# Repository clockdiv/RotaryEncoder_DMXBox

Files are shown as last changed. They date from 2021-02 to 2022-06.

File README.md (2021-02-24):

# RotaryEncoder_DMXBox
a small machine with rotary encoders to controll DMX devices

* PCB created in KiCad 5.1.9
* Code written in vscode with PlatformIO
* based on the Teensy 3.2 Project by pjrc.com

## Basic function
The values of the rotary encoders are mapped to specific DMX channels. The idea is to create a device for interactive stages like e.g. a pully hanging from the ceiling to control moving lights or similiar with it.

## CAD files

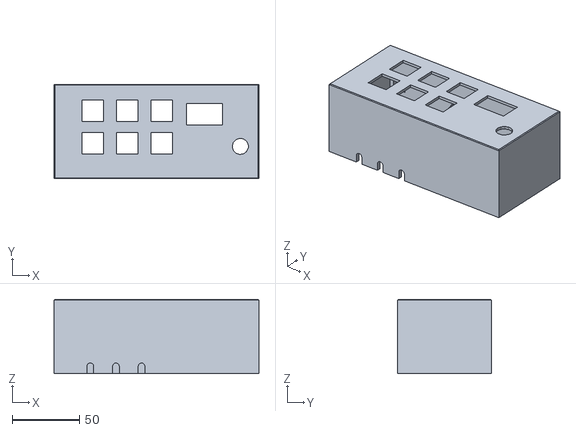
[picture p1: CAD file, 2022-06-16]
box/20210312 Gehäuse.stl
152.0 x 70.0 x 55.0

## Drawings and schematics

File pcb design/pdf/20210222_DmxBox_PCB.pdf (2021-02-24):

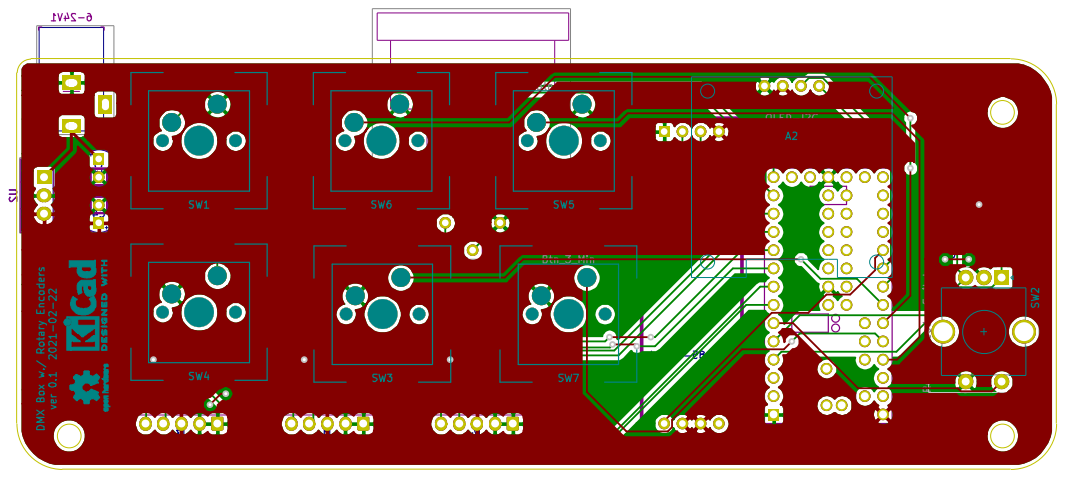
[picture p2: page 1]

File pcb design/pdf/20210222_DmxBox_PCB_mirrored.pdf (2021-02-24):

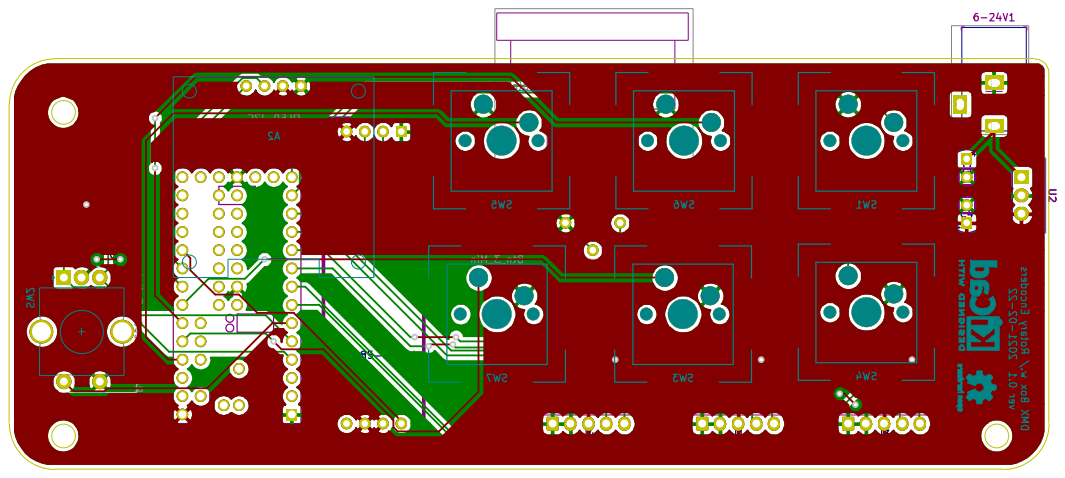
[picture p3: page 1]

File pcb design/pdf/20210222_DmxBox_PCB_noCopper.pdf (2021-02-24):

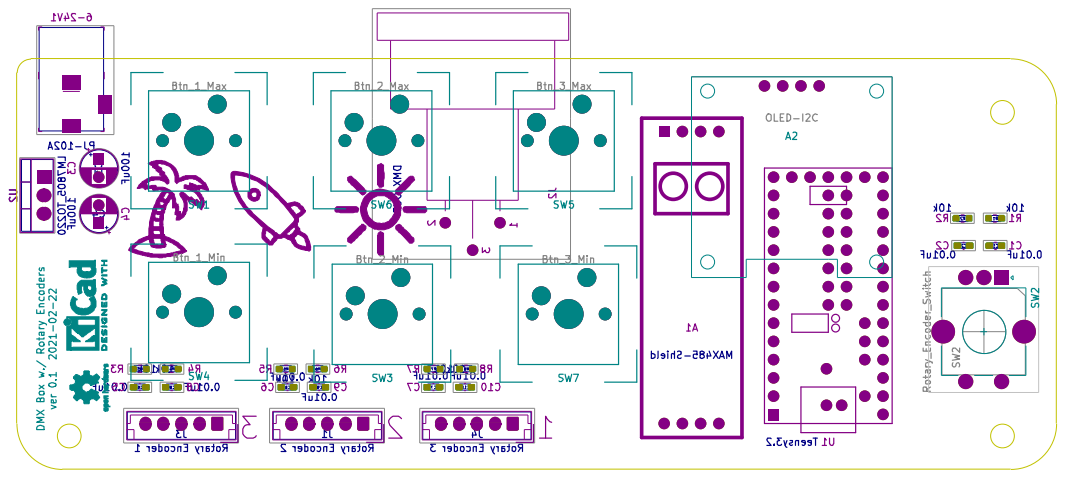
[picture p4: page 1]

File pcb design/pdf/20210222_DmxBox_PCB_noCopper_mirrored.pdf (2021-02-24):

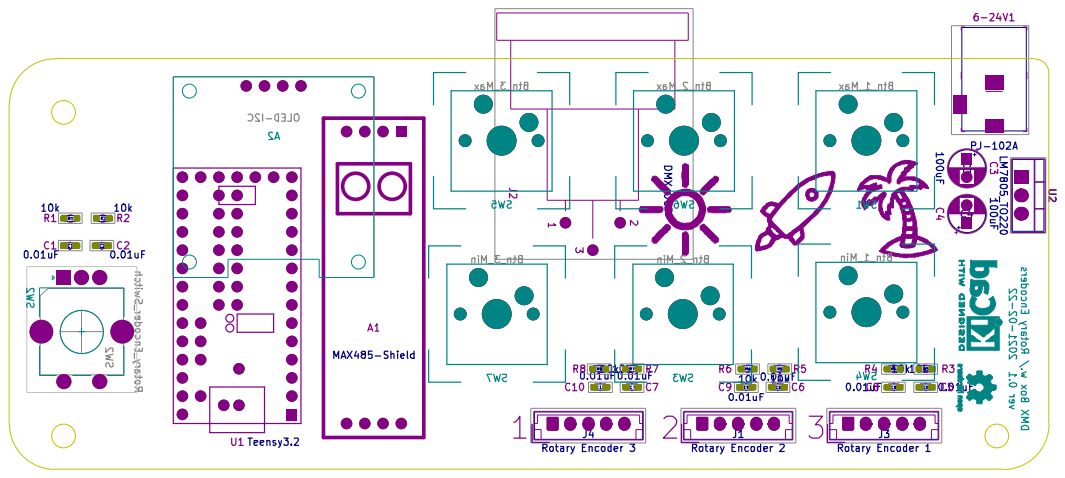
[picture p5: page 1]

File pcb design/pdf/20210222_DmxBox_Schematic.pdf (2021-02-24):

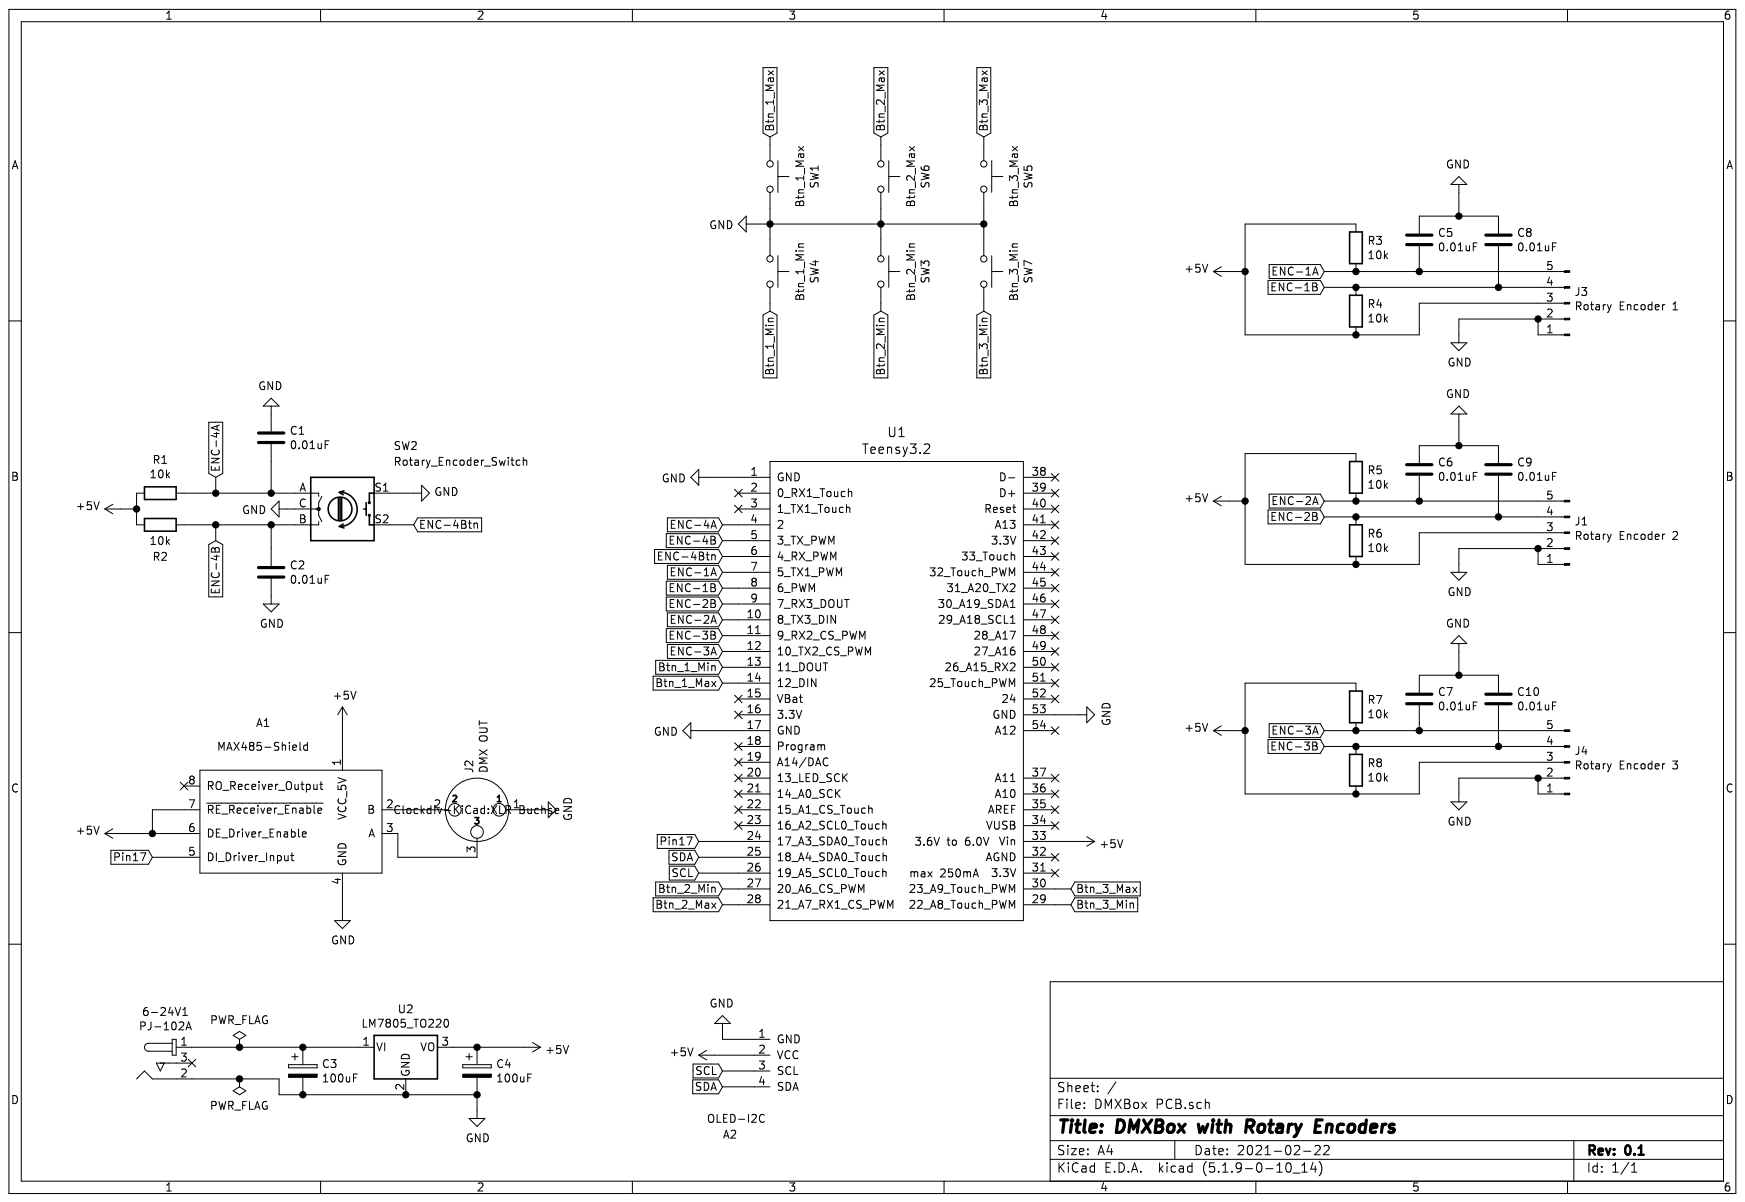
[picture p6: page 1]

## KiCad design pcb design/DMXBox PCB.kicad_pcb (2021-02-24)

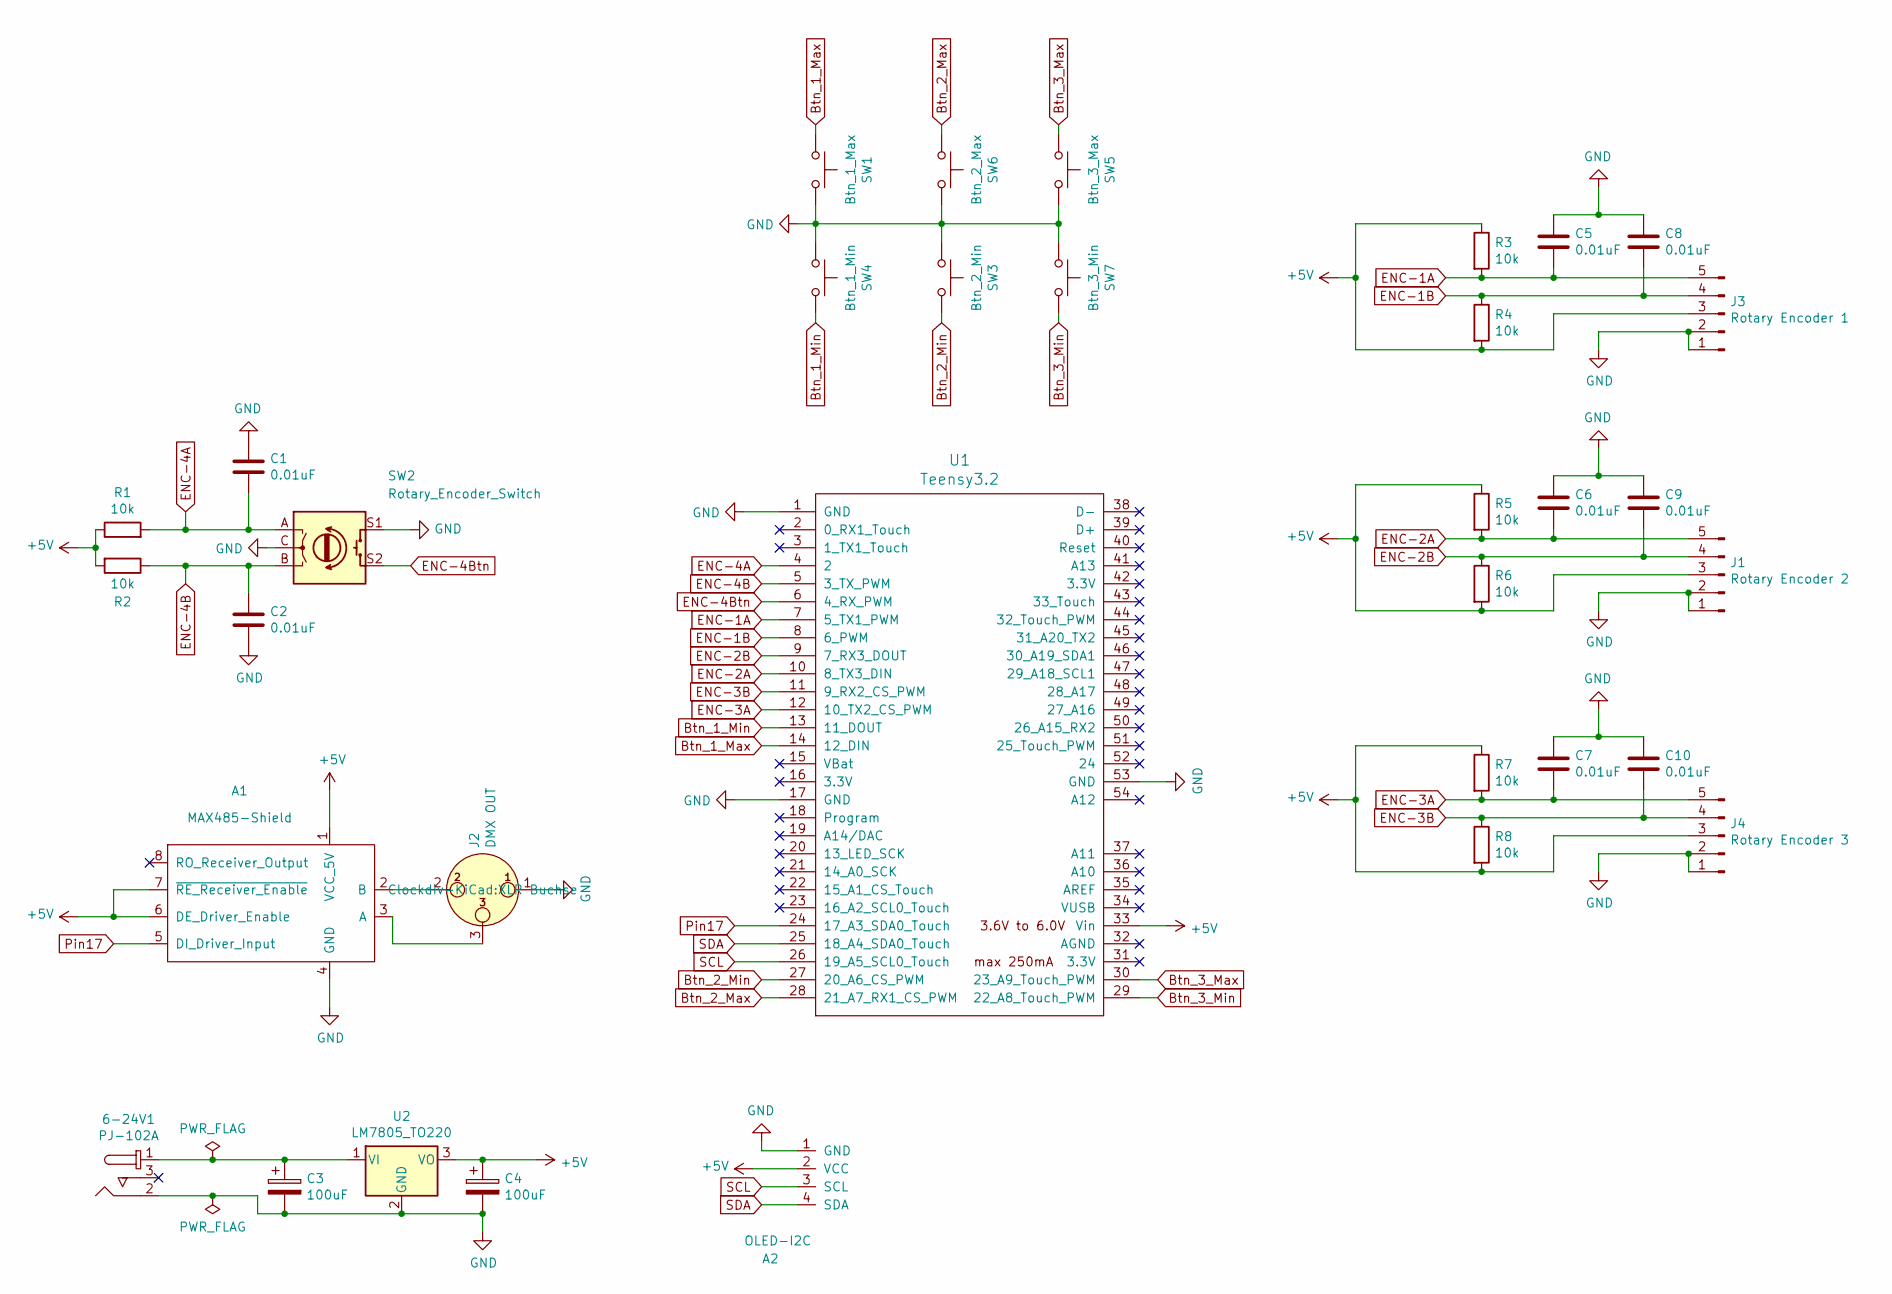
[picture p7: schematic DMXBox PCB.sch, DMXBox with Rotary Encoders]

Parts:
6-24V1: PJ-102A; Barrel_Jack_5.5mmODx2.1mmID_PJ-102A; MPN PJ-102A; Digi-Key_PN CP-102A-ND
A1: MAX485-Shield
A2: OLED-I2C
C1, C2, C5, C6, C7, C8, C9, C10: 0.01uF; C_0603_1608Metric_Pad1.08x0.95mm_HandSolder
C3, C4: 100uF; CP_Radial_D5.0mm_P2.50mm
J1: Rotary Encoder 2; JST_EH_B5B-EH-A_1x05_P2.50mm_Vertical
J2: DMX OUT; XLR Buchse
J3: Rotary Encoder 1; JST_EH_B5B-EH-A_1x05_P2.50mm_Vertical
J4: Rotary Encoder 3; JST_EH_B5B-EH-A_1x05_P2.50mm_Vertical
R1, R2, R3, R4, R5, R6, R7, R8: 10k; R_0603_1608Metric_Pad0.98x0.95mm_HandSolder
SW1: Btn_1_Max; CherryMX_PCBmount_NoDiodeNoLED
SW2: Rotary_Encoder_Switch; RotaryEncoder_Alps_EC11E-Switch_Vertical_H20mm_CircularMoun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
SW3: Btn_2_Min; CherryMX_PCBmount_NoDiodeNoLED
SW4: Btn_1_Min; CherryMX_PCBmount_NoDiodeNoLED
SW5: Btn_3_Max; CherryMX_PCBmount_NoDiodeNoLED
SW6: Btn_2_Max; CherryMX_PCBmount_NoDiodeNoLED
SW7: Btn_3_Min; CherryMX_PCBmount_NoDiodeNoLED
U1: Teensy3.2; Teensy30_31_32_All_Pins
U2: LM7805_TO220; TO-220-3_Vertical

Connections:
+5V: A1.1 (VCC_5V), A1.6 (DE_Driver_Enable), A1.7 (~RE_Receiver_Enable), A2.2 (VCC), C4.1, J1.3, J3.3, J4.3, R1.1, R2.2, R3.1, R4.2, R5.1, R6.2, R7.1, R8.2, U1.33 (Vin), U2.3 (VO)
Btn_1_Max: SW1.1, U1.14 (12_DIN)
Btn_1_Min: SW4.2, U1.13 (11_DOUT)
Btn_2_Max: SW6.1, U1.28 (21_A7_RX1_CS_PWM)
Btn_2_Min: SW3.2, U1.27 (20_A6_CS_PWM)
Btn_3_Max: SW5.1, U1.30 (23_A9_Touch_PWM)
Btn_3_Min: SW7.2, U1.29 (22_A8_Touch_PWM)
ENC-1A: C5.2, J3.5, R3.2, U1.7 (5_TX1_PWM)
ENC-1B: C8.2, J3.4, R4.1, U1.8 (6_PWM)
ENC-2A: C6.2, J1.5, R5.2, U1.10 (8_TX3_DIN)
ENC-2B: C9.2, J1.4, R6.1, U1.9 (7_RX3_DOUT)
ENC-3A: C7.2, J4.5, R7.2, U1.12 (10_TX2_CS_PWM)
ENC-3B: C10.2, J4.4, R8.1, U1.11 (9_RX2_CS_PWM)
ENC-4A: C1.2, R1.2, SW2.A, U1.4 (2)
ENC-4B: C2.1, R2.1, SW2.B, U1.5 (3_TX_PWM)
ENC-4Btn: SW2.S2, U1.6 (4_RX_PWM)
GND: 6-24V1.2, A1.4 (GND), A2.1 (GND), C1.1, C2.2, C3.2, C4.2, C5.1, C6.1, C7.1, C8.1, C9.1, C10.1, J1.1, J1.2, J2.1, J3.1, J3.2, J4.1, J4.2, SW1.2, SW2.C, SW2.S1, SW3.1, SW4.1, SW5.2, SW6.2, SW7.1, U1.1 (GND), U1.17 (GND), U1.53 (GND), U2.2 (GND)
unnamed: 6-24V1.1, C3.1, U2.1 (VI)
unnamed: A1.2 (B), J2.2
unnamed: A1.3 (A), J2.3
Pin17: A1.5 (DI_Driver_Input), U1.24 (17_A3_SDA0_Touch)
SCL: A2.3 (SCL), U1.26 (19_A5_SCL0_Touch)
SDA: A2.4 (SDA), U1.25 (18_A4_SDA0_Touch)

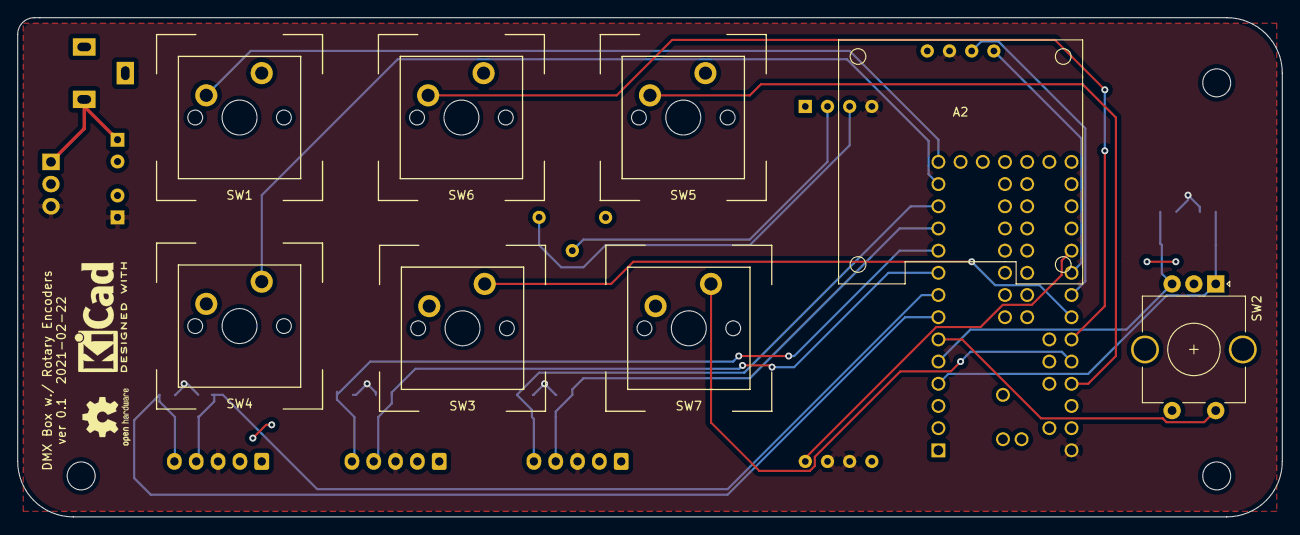
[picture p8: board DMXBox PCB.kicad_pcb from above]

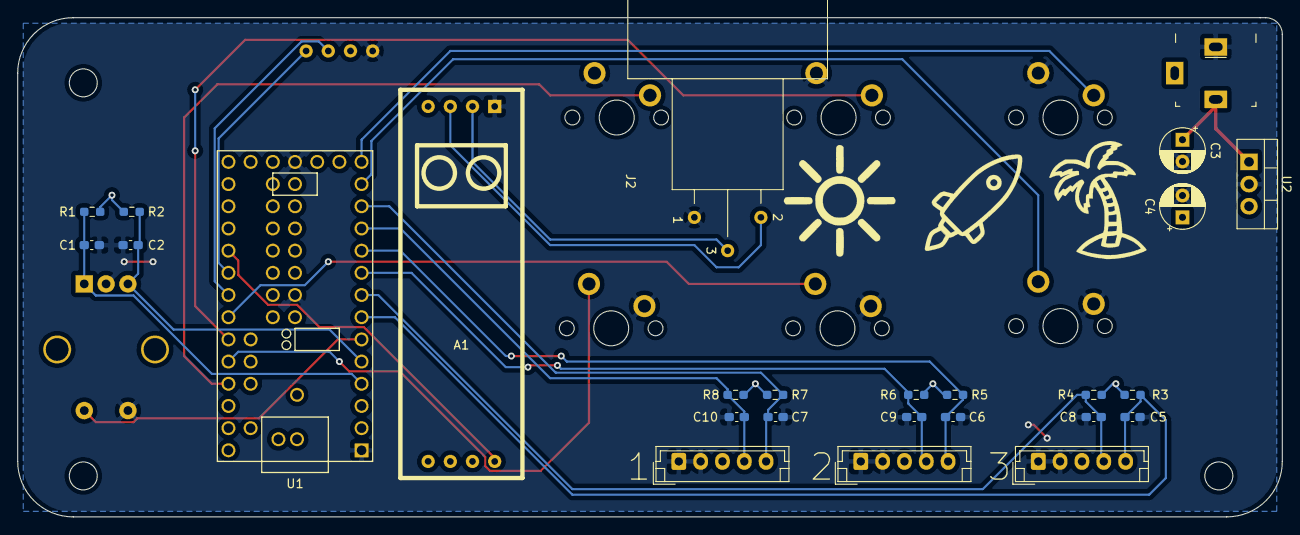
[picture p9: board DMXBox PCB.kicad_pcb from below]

Board: 2 copper layers, 144.8 x 57.2 mm, 34 parts (26 on the bottom side), 23 nets.

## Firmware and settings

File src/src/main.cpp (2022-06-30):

#include <SPI.h>
#include <Wire.h>
#include <Adafruit_GFX.h>
#include <Adafruit_SSD1306.h>
#include <Encoder.h>
#include <Bounce2.h>
#include <DmxSimple.h>
#include "Axis.h"

#define SCREEN_ADDRESS 0x3C

#define DEBOUNCEINTERVAL 20

Adafruit_SSD1306 display(128, 64, &Wire, -1);

Encoder encoder(3, 2);
Encoder encoderX(6, 5);
Encoder encoderY(8, 7);
Encoder encoderZ(10, 9);

Bounce selectButton = Bounce();
Bounce buttonXUp = Bounce();
Bounce buttonXDown = Bounce();
Bounce buttonYUp = Bounce();
Bounce buttonYDown = Bounce();
Bounce buttonZUp = Bounce();
Bounce buttonZDown = Bounce();

Axis axisX, axisY, axisZ;

int32_t encoderValue  = -999;

enum statesEnum {IDLE, WAIT_FOR_BUTTON, WAIT_FOR_BUTTON_TIMEOUT, SET_DMX_CHANNEL};
uint8_t state = IDLE, nextState = IDLE;

Axis* selectedAxis = &axisX;

unsigned long currentMillis, stateEnteredMillis, lastTimeValueSend;
unsigned long waitForButtonTimeout = 1000;
unsigned long sendValueInterval = 1000/25;
Axis* axisSetup;

void displayValues() {
    display.clearDisplay();
    display.invertDisplay(false);

    display.setTextSize(1); // Draw 2X-scale text
    display.setTextColor(SSD1306_WHITE);
    display.setCursor(0, 0);

    display.print(axisX.getValue());
    display.print(" => ");
    display.print(axisX.getDMXValue());
    display.print(" (ch: ");
    display.print(axisX.getDMXChannel());
    display.print(")");
    display.println();

    display.print(axisY.getValue());
    display.print(" => ");
    display.print(axisY.getDMXValue());
    display.print(" (ch: ");
    display.print(axisY.getDMXChannel());
    display.print(")");
    display.println();

    display.print(axisZ.getValue());
    display.print(" => ");
    display.print(axisZ.getDMXValue());
    display.print(" (ch: ");
    display.print(axisZ.getDMXChannel());
    display.print(")");
    display.println();

    display.display();      // Show initial text
}

void sendDMX() {
    DmxSimple.write(axisX.getDMXChannel(), axisX.getDMXValue());
    DmxSimple.write(axisY.getDMXChannel(), axisY.getDMXValue());
    DmxSimple.write(axisZ.getDMXChannel(), axisZ.getDMXValue());
}

void displayInfoMsg(String msg) {
    display.clearDisplay();
    display.setTextSize(2);
    display.invertDisplay(true);
    display.setCursor(0, 24);
    display.println(msg);
    display.display();
}

void stateMachineRun() {
  switch (state)
  {

  case IDLE:
    // send DMX Values if one axis has changed
    if (axisX.changed() || axisY.changed() || axisZ.changed()) {
      displayValues();
      sendDMX();
    }
    if(selectButton.fallingEdge()){
      stateEnteredMillis = millis();
      nextState = SET_DMX_CHANNEL;
      state = WAIT_FOR_BUTTON;
    }

    // Send Axis to Serial
    if (currentMillis - lastTimeValueSend > sendValueInterval) {
      Serial.println(axisZ.getValue());
      lastTimeValueSend = currentMillis;
    }
    
    break;



  case WAIT_FOR_BUTTON:
    displayInfoMsg("Press 1s");
    if( currentMillis - waitForButtonTimeout > stateEnteredMillis /*|| buttonXUp.risingEdge() || buttonXDown.risingEdge() || buttonYUp.risingEdge() || buttonYDown.risingEdge() || buttonZUp.risingEdge() || buttonZDown.risingEdge()*/) {
      Serial.print("next state: ");
      Serial.println(nextState);
      state = nextState;
    }
    break;
   

  case SET_DMX_CHANNEL:
    if(selectButton.fallingEdge()){
      stateEnteredMillis = millis();
      nextState = IDLE;
      state = WAIT_FOR_BUTTON;
    }


      int32_t newencoderValue;
      newencoderValue = encoder.read() / 4;
      //delay(200);
      if(newencoderValue != encoderValue )
      {
        Serial.println(newencoderValue);
        encoderValue = newencoderValue;
      /*
        axisSetup->setDMXChannel(constrain(encoderValue, 0, 512));
        display.clearDisplay();
        display.setCursor(0,0);
        display.println(axisSetup->name);
        display.print("ch: ");
        display.println(axisSetup->getDMXChannel());
        display.print("enc: ");
        display.println(encoderValue);
        display.display();
        */
      }
      
    break;
  
  default:
    break;
  }
}

void setup() {
  Serial.begin(115200);
  //while (!Serial);
  Serial.println("Welcome!");
  DmxSimple.usePin(17);
  //DmxSimple.maxChannel(3);

  axisX.setDMXChannel(1);
  axisY.setDMXChannel(2);
  axisZ.setDMXChannel(3);
  axisX.name = "x-axis";
  axisY.name = "y-axis";
  axisZ.name = "z-axis";


  selectButton.attach(4, INPUT_PULLUP);
  selectButton.interval(DEBOUNCEINTERVAL);

  buttonXUp.attach(11, INPUT_PULLUP);
  buttonXUp.interval(DEBOUNCEINTERVAL);

  buttonXDown.attach(12, INPUT_PULLUP);
  buttonXDown.interval(DEBOUNCEINTERVAL);
  
  buttonYUp.attach(20, INPUT_PULLUP);
  buttonYUp.interval(DEBOUNCEINTERVAL);

  buttonYDown.attach(21, INPUT_PULLUP);
  buttonYDown.interval(DEBOUNCEINTERVAL);

  buttonZUp.attach(22, INPUT_PULLUP);
  buttonZUp.interval(DEBOUNCEINTERVAL);

  buttonZDown.attach(23, INPUT_PULLUP);
  buttonZDown.interval(DEBOUNCEINTERVAL);

  // SSD1306_SWITCHCAPVCC = generate display voltage from 3.3V internally
  if(!display.begin(SSD1306_SWITCHCAPVCC, SCREEN_ADDRESS)) {
    Serial.println(F("SSD1306 allocation failed"));
    for(;;); // Don't proceed, loop forever
  }

  lastTimeValueSend = millis();
}

void loop() {
  currentMillis = millis();

  axisX.setValue(encoderX.read() / 4);
  axisY.setValue(encoderY.read() / 4);
  axisZ.setValue(encoderZ.read() / 4);

  // update all buttons
  selectButton.update();
  buttonXUp.update();
  buttonXDown.update();
  buttonYUp.update();
  buttonYDown.update();
  buttonZUp.update();
  buttonZDown.update();

  stateMachineRun();
}

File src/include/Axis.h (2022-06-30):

#include <Arduino.h>
#include <Encoder.h>

class Axis {
private:
    int32_t encoderValue = 0;
    int32_t clampedAxisValue = 0;          // clamped value of axis
    int32_t minEncoderValue = 0;
    int32_t maxEncoderValue = 3000; 
    uint8_t dmxValue = 0;
    bool hasChanged = false;
    uint16_t dmxChannel = 0;
    void mapDMXValue();

public:
    String name;

    void setValue(int32_t encoderValueNew);

    void setMinValue() { minEncoderValue = encoderValue; mapDMXValue(); }
    void setMaxValue() { maxEncoderValue = encoderValue; mapDMXValue(); }
    int32_t getValue() { return encoderValue; }
    int32_t getClampedAxisValue() { return clampedAxisValue; }
    uint8_t getDMXValue() { return dmxValue; }
    uint16_t getDMXChannel() {return dmxChannel; }
    void setDMXChannel(uint16_t ch) { dmxChannel = ch; }
    bool changed();
};

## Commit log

2021-02-24 initial commit hardware design
    [DMXBox PCB-B_Cu.gbr, DMXBox PCB-B_Mask.gbr, DMXBox PCB-B_Paste.gbr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]
2022-06-16 rebuild
    rebuild most of the code:
    - encoder on z-axis sends value to Serial
    [20210312 Gehäuse.stl]
2022-06-30 clamped axis
    added a variable for a clamped axis value
